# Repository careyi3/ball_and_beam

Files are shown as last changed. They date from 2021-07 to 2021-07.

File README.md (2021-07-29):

# Ball and Beam

This repo is to record all of the resources that went into making the ball and beam rig that I talk about in [this article](https://iancarey.ie/blog/ballandbeam)

Feel free to browse around and copy from this what you like. Don't hesitate to ask questions! In each folder you will find a README with some details on each subject.

Ball and Beam rig performing disturbance rejection

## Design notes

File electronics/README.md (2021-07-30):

# Electronics

This system is fairly simple to wire up, it's mostly just connecting up off the shelf components, it doesn't really involve much deep understanding of electronics. I am not going to go into huge detail on how the system works electronically but I will mention a few important gotchas. Firstly and main two components are an Arduino Nano microcontroller and a DRV8825 stepper driver.

The motor driver board has in it's specs that you need to attach a capacitor between the positive and negative 12V DC input. I initially ignored it as I didn't have the value of cap they mentioned. DO NOT IGNORE THIS! I fried two boards and had no idea why, I added a 22uF cap I had lying around and haven't had any issues since.

The motor driver board needs 12V to run, so make sure you have a decent 12V power supply. Also depending on your motor, you will need to be able to draw somewhere around 1-2A from the supply at this voltage. So make sure your supply can do this. Another note on supply voltages and and currents, the motor driver board has a small pot on it called the trim pot. This pot sets the current that the motor can draw from the board. I recommend you do some reading around this as all motors are different and I have no idea what kind you will pick. In short, if you motor is squealing, it might be running with the wrong drive current, you can tweak it and see.

Finally, the circuit here won't work with just the 12V power supply. As I decided that I always wanted to plot the ball position etc via the computer, the Arduino microcontroller needs to be powered via it's USB for the system to work. This means either having it connected to the computer or an external 5V power supply. DO NOT CONNECT THE ARDUINO TO THE 12V DC SUPPLY.

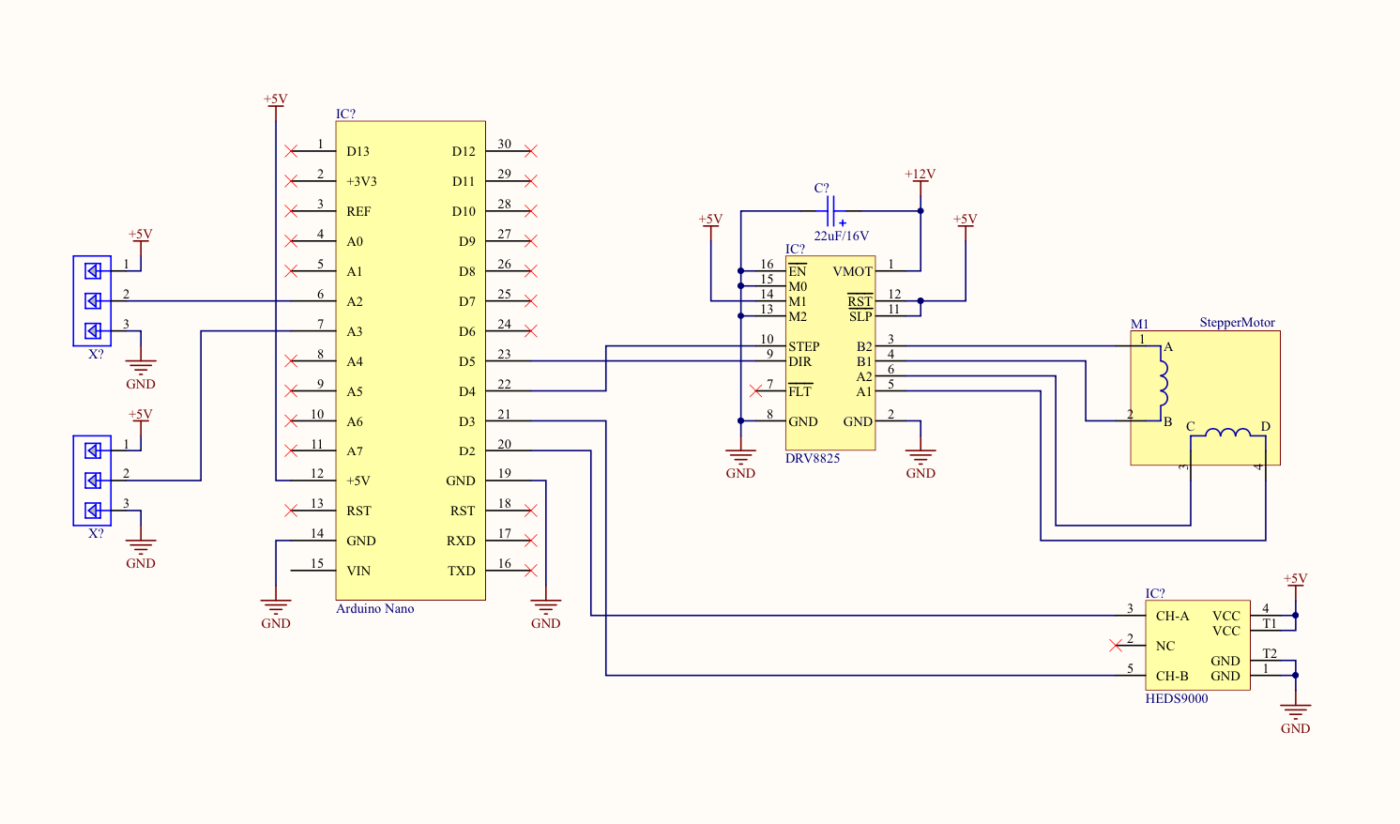
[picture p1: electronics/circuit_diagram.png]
Circuit Diagram


## Breadboard vs Protoboard vs PCB

The system worked fine for me when assembled on a breadboard. However, I wanted to put this on a shelf for display. I decided to build my circuit onto a piece of solderable protoboard. You don't need to do this, it won't make the rig any better but will make it look nicer. Even better still, if you design a PCB (which I just wasn't bothered doing), it'll look even nicer!!

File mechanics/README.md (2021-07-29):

# Mechanics

Here you will find the STL files used to 3d print the main body, beam end caps and shaft coupler for the rig. THe rig I built was printed with PLA.

Aside from the 3d printed parts, there are a few other mechanical parts listed below. Most parts were used off the shelf however I also fabricated some of the parts from 5mm stainless steel rod.

## Parts List

| Part | Quantity | Dimensions |
| --- | --- | --- |
| Drive Shaft | 1 | Diameter 5mm, Length 60mm |
| Beam Arms | 4 | Diameter 5mm, Length 250mm |
| 20 Tooth Timing Pulley | 1 | OD 16mm, ID 5mm, Width 7mm |
| 60 Tooth Timing Pulley | 1 | OD 42MM, ID 5mm, Width 7mm |
| Timing Belt | 1 | Length 200mm, Width 6mm |
| 625RS Bearing | 4 | OD 16mm, ID 5mm, Thickness 5mm |
| M5 Bolt | 1 | Length 30mm |
| M5 Nut | 1 | N/A |
| 5mm Washers | 4 | N/A |
| M3 Bolt | 2 | Length 30mm |

## Assembly

Assembly is straight forward enough for this machine. Firstly, I recommend cleaning up all 3d printed parts to remove excess material. Be careful with this as some parts are designed to be a compression fit, so don't take too much off, just enough so that the parts can slip together.

Firstly, press two of the bearings into their receiving slots in the main body of the machine. Next, place the motor into it's slot and screw it into place using two M3 bolts. Next, attach the small pulley to the motor shaft and tighten via the set screws.

Next, insert the drive shaft into the two fitted bearings and add the larger pulley, again securing with the set screws. Place the belt between the two pulleys. If it is too tight, remove one of the pulleys, attach the belt and then with the belt under tension, place the pulley back on the shaft.

Slot the two remaining bearings with washers either side onto the M5 bolt. Insert this into the slot on the body such that the bearings push against the belt (this is the belt tensioner). Once happy with the position, add the M5 nut and tighten.

Take each end of the beams end caps and using a 5mm metal drill bit, bore out the centres so that they are a snug fit over the 5mm beam arm shafts. Press one end in fully. Take the shaft coupler and pass the closed ring over the furthers bar of the beam arm. Twist the arms so that the lower open jaw of the shaft coupler snaps into place around the bottom shaft.

Finally press the shaft coupler onto the drive shaft.

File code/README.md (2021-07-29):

# Code

The code for this rig is fairly simple Arduino code. The code was designed to be run on an Arduino Nano but should work fine on an Uno with no alterations.

## Prerequisites

There are two libraries used in this code, one for reading the rotary encoder and another for computing moving averages. These must be installed via the Arduino Library Manager.

[MovingAverage](https://www.arduino.cc/reference/en/libraries/movingaverager/)

[Encoder](https://www.arduino.cc/reference/en/libraries/encoder/)

**NOTE: The [reference website](https://www.pjrc.com/teensy/td_libs_Encoder.html) for this library is fantastic and a great resource if you don't already know how an optical rotary encoder works.**

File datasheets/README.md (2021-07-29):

# Datasheets

Here you will find data sheets for most of the electronic components used in the build. The only thing I couldn't find a datasheet for was the exact stepper motor I used. I found the stepper in my parts box and have no idea where is came from. However, any 4 wire NEMA17 sized stepper that you can fit with a HEDS 9000/9100 optical encoder should work fine. Also worth noting for the rest of the mechanical components, the stepper had a 5mm diameter shaft.

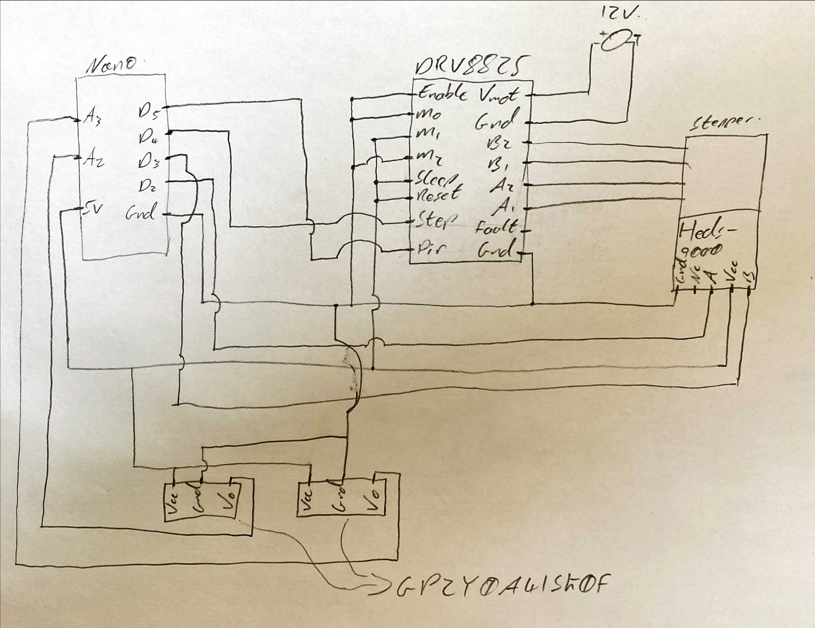
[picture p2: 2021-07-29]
electronics/hand_drawn_circuit_diagram.jpg

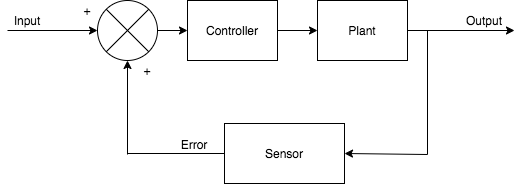
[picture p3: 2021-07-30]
images/compensated_system.png

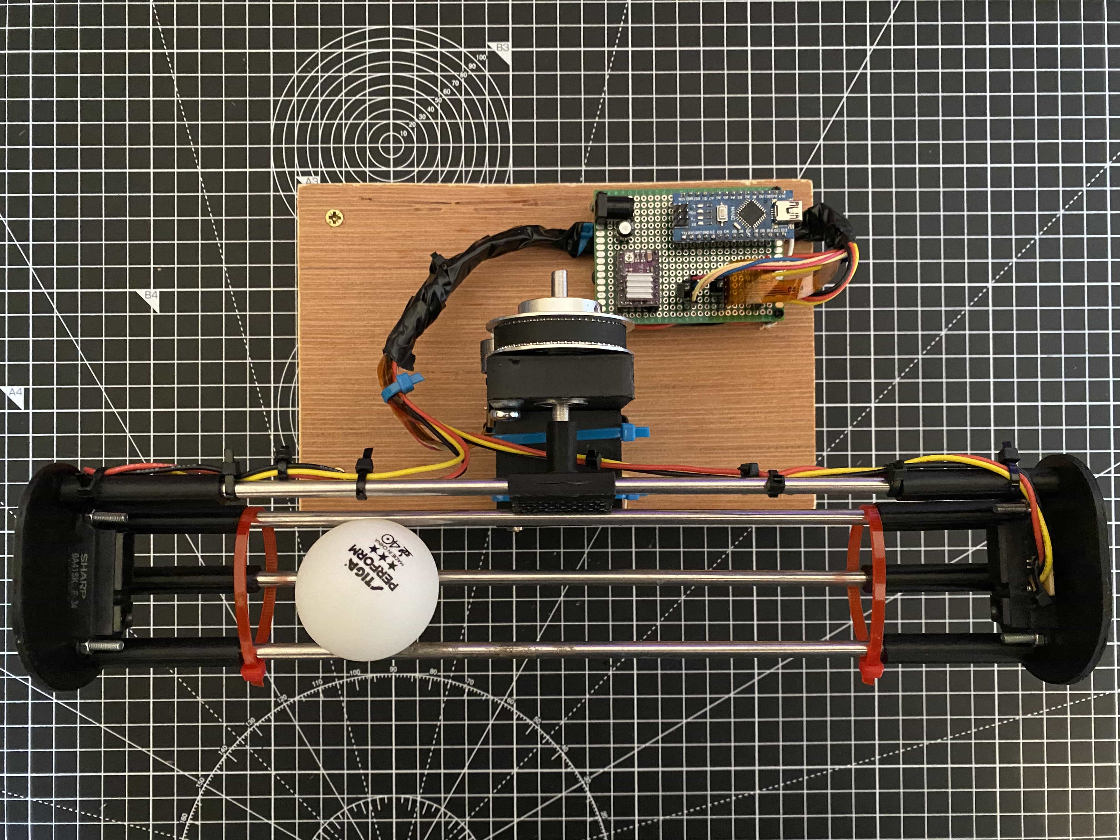
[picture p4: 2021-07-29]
images/top.jpg

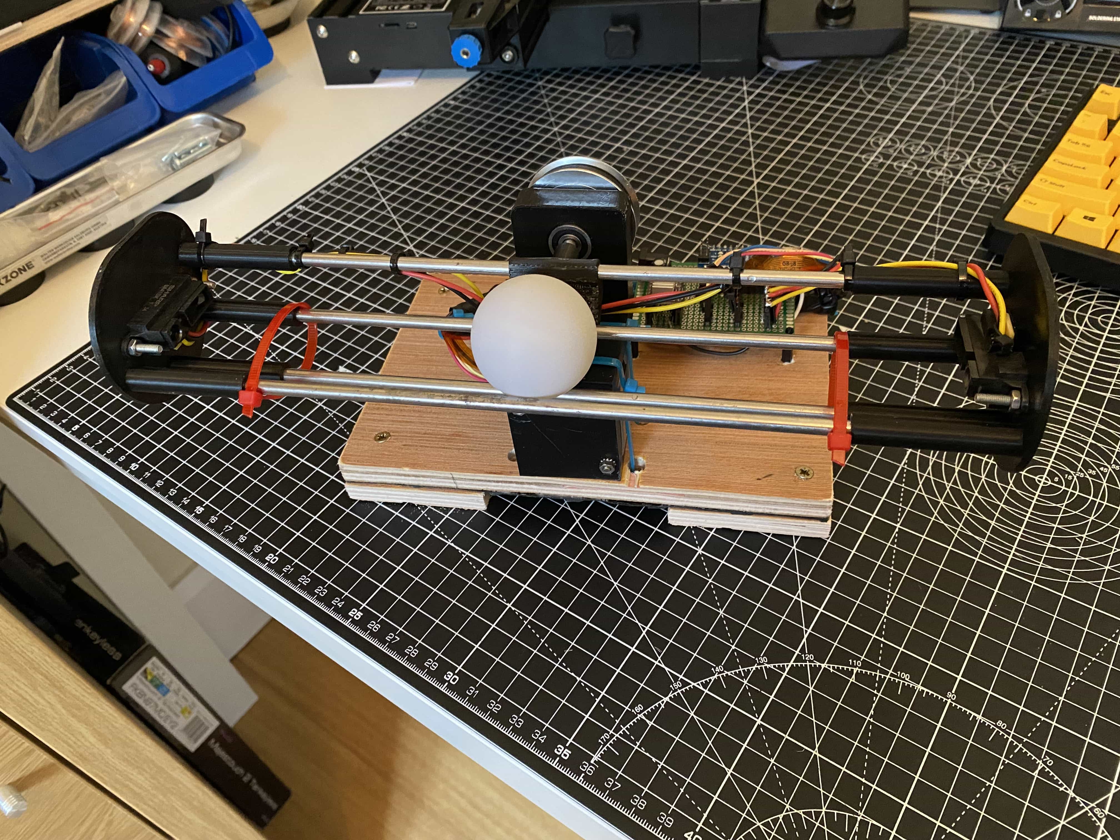
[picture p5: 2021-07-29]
images/front.jpg

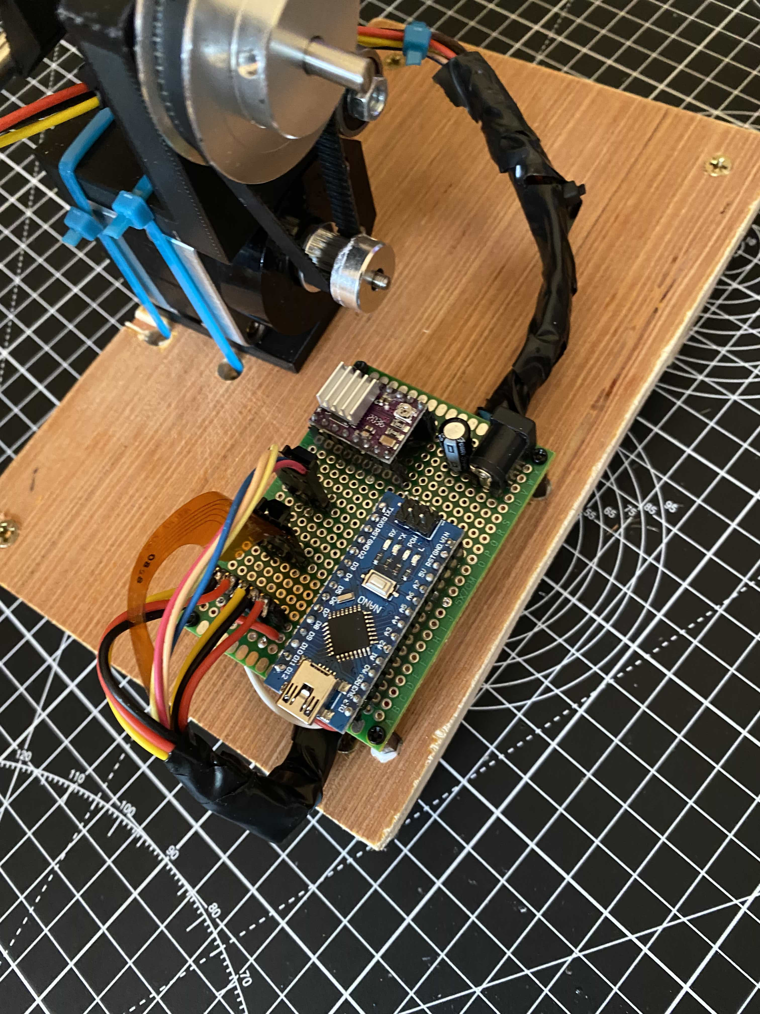
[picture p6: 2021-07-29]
images/circuit_board.jpg

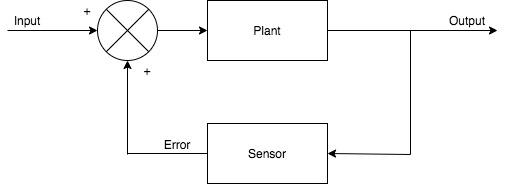
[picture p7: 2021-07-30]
images/uncompensated_system.png

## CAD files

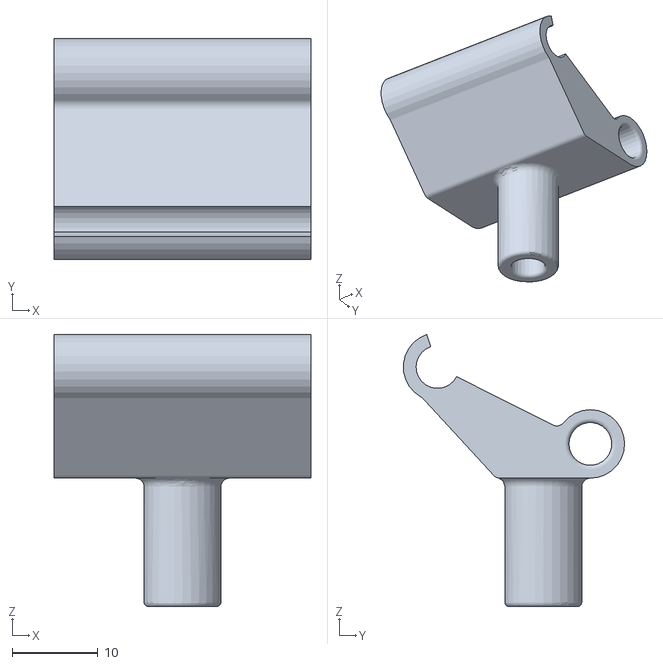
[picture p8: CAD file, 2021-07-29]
mechanics/shaft_coupler.stl
30.0 x 25.8 x 31.8

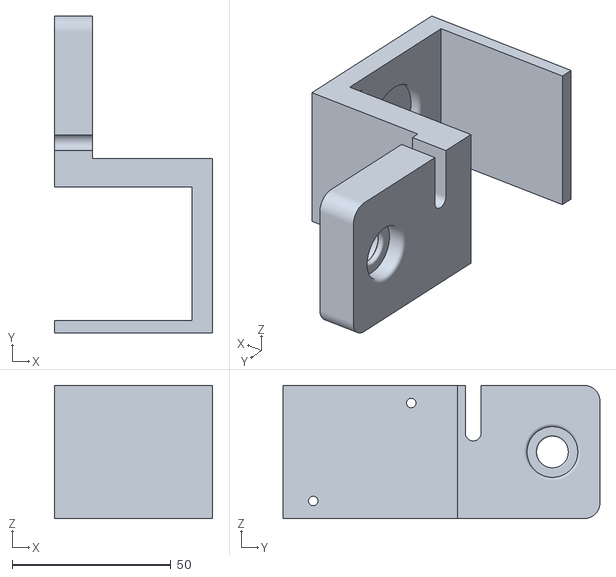
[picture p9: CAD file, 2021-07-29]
mechanics/body.stl
50.0 x 100.0 x 42.0

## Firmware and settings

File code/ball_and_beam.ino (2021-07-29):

#define ENCODER_OPTIMIZE_INTERRUPTS
#include <Encoder.h>       // https://www.arduino.cc/reference/en/libraries/encoder/
#include <MovingAverage.h> // https://www.arduino.cc/reference/en/libraries/movingaverager/

const uint8_t STEP = DD4;
const uint8_t DIR = DD5;
const uint8_t CH1 = DD2;
const uint8_t CH2 = DD3;
const uint8_t SENSOR_LEFT = A2;
const uint8_t SENSOR_RIGHT = A3;
const int FILTER_LENGTH = 80; // Length of the moving average filter, larger value will make it smoother but will also respond more slowly to changing inputs.
const int SPEED = 200;        // Effectively sets the step speed of the motor. In reality, sets the period in microseconds of the drive signal to the stepper driver. Smaller values means faster steps.
const int INTERVAL = 1;       // Delay in microseconds to set timing for the main loop.

const bool LEFT = 1;
const bool RIGHT = 0;

int left_position, right_position = 0; // Raw sensor values for left and right ball position.

MovingAverage left_filter(FILTER_LENGTH);  // Left ball position filter.
MovingAverage right_filter(FILTER_LENGTH); // Right ball position filter.

double left_position_filtered, right_position_filtered, position, offset = 0; // Filtered positions, final position and offset values for ball position.

double dt, timer = 0; // Timer and loop time counters.

double error_old, integral = 0; // PID variables.

int encoder_position = 0; // Raw rotary encoder position.

double angle, desired_angle = 0; // Angles.

Encoder encoder(CH1, CH2); // Optical rotary encoder.

void setup()
{
  Serial.begin(9600);
  pinMode(STEP, OUTPUT);
  pinMode(DIR, OUTPUT);

  digitalWrite(STEP, LOW);
  digitalWrite(DIR, LOW);

  encoder.write(0); // Set encoder to 0 position. (this means you need to have the beam level when you turn on the rig)

  // Calculate a stable 0 position for the optical position sensors by accumulating 5x the filter length and computing the 0 offset from this.
  for (int i = 0; i < FILTER_LENGTH * 5; i++)
  {
    readSensors(false); // false because we want the raw values here WITHOUT the offset applied.
  }
  offset = 0 - position;
}

// Usually the main working loop, in this case, we are just using it to keep time work() is where the work is done!
void loop()
{
  dt = (micros() - timer) / 1000000;
  timer = micros();

  work(); // Main working method.

  while (micros() - timer < INTERVAL)
  {
    //NOOP
  }
}

void work()
{
  readSensors(true);     // Read ball position.
  double moveTo = pid(); // Calculate angle to move to.
  moveToAngle(moveTo);   // Move to angle.

  /*
    Log data.
    
    logAngle() and logPosition() output data to be plotted using the Serial Plotter tool in the arduino IDE.
    
    logData() will output angle and ball position in CSV style for the Serial Monitor.
    
    NOTE: Using this changes the speed that the system runs at. Removing all of them will change the system dynamic and will require the PID controller to be tuned again.
  */

  //logAngle();
  //logPosition();
  logData();
}

double pid()
{
  double error;
  double derivative;
  error = (0 - position);
  integral += error * dt;
  derivative = (error - error_old) / dt;
  error_old = error;

  double kp = 0.07;
  double ki = 0.05;
  double td = 0.06;
  return (kp * error) + (ki * integral) + (td * derivative);
}

void moveToAngle(int newAngle)
{
  // These limits are to stop the rig hitting the table.
  if (newAngle > 25)
  {
    newAngle = 25;
  }

  if (newAngle < -25)
  {
    newAngle = -25;
  }

  double diff = newAngle - angle;
  double absDiff = abs(diff);

  int count = 0;
  int res = 4;                            // Setting a resolution because our motor us stepping in quarter stepping mode, so we want to get to within a quarter of a step.
  while (absDiff >= 1 / res && count < 3) // This loop allows the system to compensate up to 2 times for lost steps.
  {
    if (diff > 0)
    {
      step((int)absDiff * res, RIGHT);
    }
    else
    {
      step((int)absDiff * res, LEFT);
    }

    readSensors(true);
    diff = newAngle - angle;
    absDiff = abs(diff);
    count++;
  }
}

void step(int steps, bool direction)
{
  digitalWrite(DIR, direction);
  for (int i = 0; i < steps; i++)
  {
    digitalWrite(STEP, LOW);  // Stepper performs one step for each LOW -> HIGH transition.
    delayMicroseconds(SPEED); // Delay to set step speed.
    digitalWrite(STEP, HIGH);
    delayMicroseconds(SPEED);
    digitalWrite(STEP, LOW);
  }
}

void readSensors(bool withOffSet)
{
  encoder_position = encoder.read();
  angle = -1 * encoder_position / 16.0;                    // Scaling the encoder to give us roughly correct degrees.
  left_position = 19.7 + (analogRead(SENSOR_LEFT) / 3.33); // Scales the sensors taking into account ball diameter giving us an output in mm.
  left_position_filtered = left_filter.addSample((double)left_position);
  right_position = 19.7 + (analogRead(SENSOR_RIGHT) / 3.33);
  right_position_filtered = right_filter.addSample((double)right_position);
  position = right_position_filtered - left_position_filtered;

  if (withOffSet)
  {
    position = position + offset;
  }
}

void logPosition()
{
  Serial.print("position:");
  Serial.println(position);
}

void logAngle()
{
  Serial.print("angle:");
  Serial.println(angle);
}

void logData()
{
  Serial.print("position:");
  Serial.print(position);
  Serial.print(", ");
  Serial.print("angle:");
  Serial.println(angle);
}
